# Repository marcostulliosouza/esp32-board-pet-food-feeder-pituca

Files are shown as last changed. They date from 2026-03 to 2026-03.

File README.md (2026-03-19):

# ESP32 Pet Food Feeder – Pituca

<div align="center">
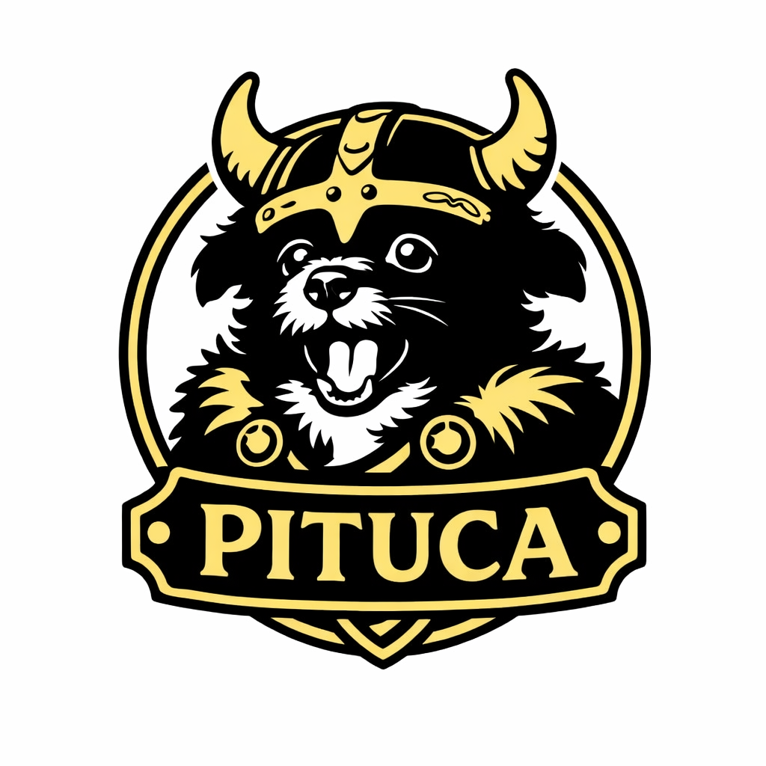
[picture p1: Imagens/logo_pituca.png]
  
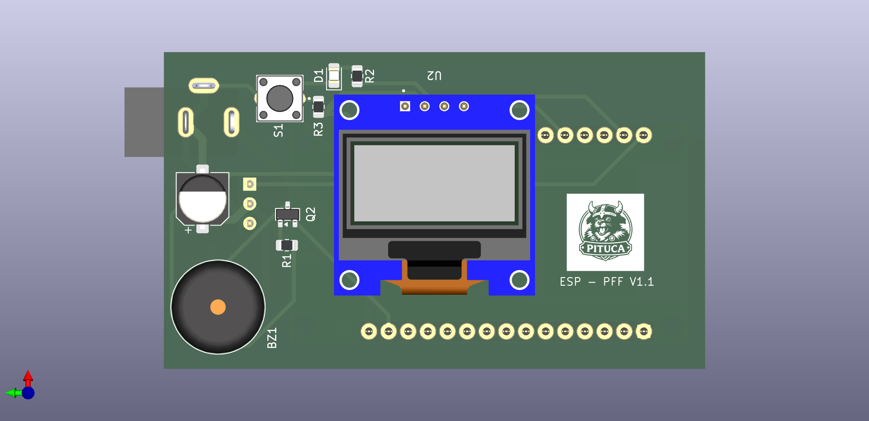
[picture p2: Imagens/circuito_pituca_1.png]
  
</div>

Placa eletrônica baseada no ESP32 desenvolvida para um alimentador automático de pets, permitindo controle preciso de horários e porções de ração, com possibilidade de integração via Wi-Fi.

## Visão geral

Este projeto foi criado para automatizar a alimentação de animais domésticos de forma confiável e prática. A placa utiliza um módulo ESP32 encaixado via headers (socket), facilitando montagem, manutenção e substituição do microcontrolador.

## Funcionalidades

*  Programação de horários de alimentação
*  Conectividade Wi-Fi (ESP32)
*  Alimentação externa regulada
*  Interface para periféricos (motores, sensores, etc.)
*  Design modular com ESP32 removível

##  Hardware

* ESP32 DevKit (via socket)
* Conectores para expansão (GPIOs)
* Trilhas dimensionadas para alimentação e sinais
* Plano de GND em múltiplas camadas

##  Status do projeto

Em desenvolvimento

##  Imagens
imagem_placa_pituca
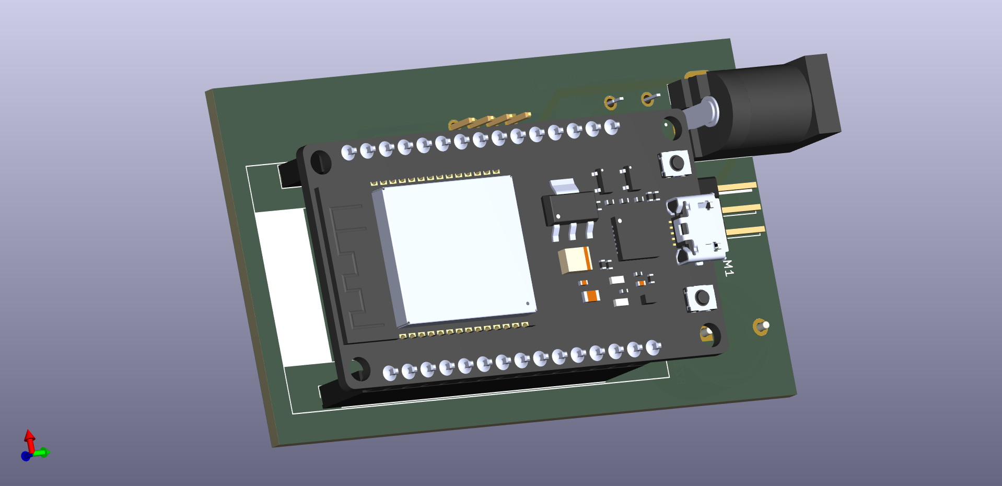
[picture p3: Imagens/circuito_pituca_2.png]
imagem_placa_pituca

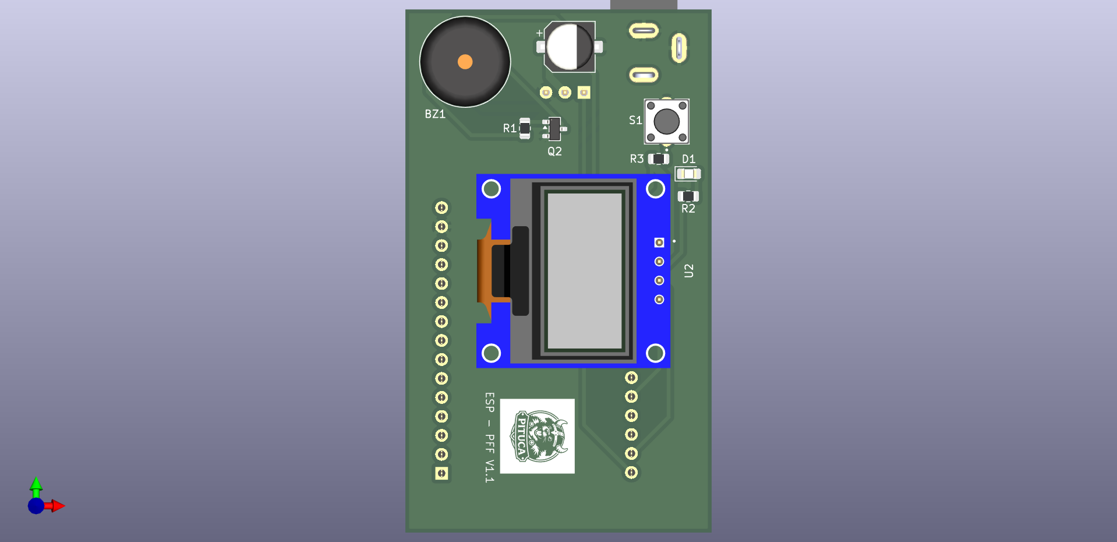
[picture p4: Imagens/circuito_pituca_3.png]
imagem_placa_pituca

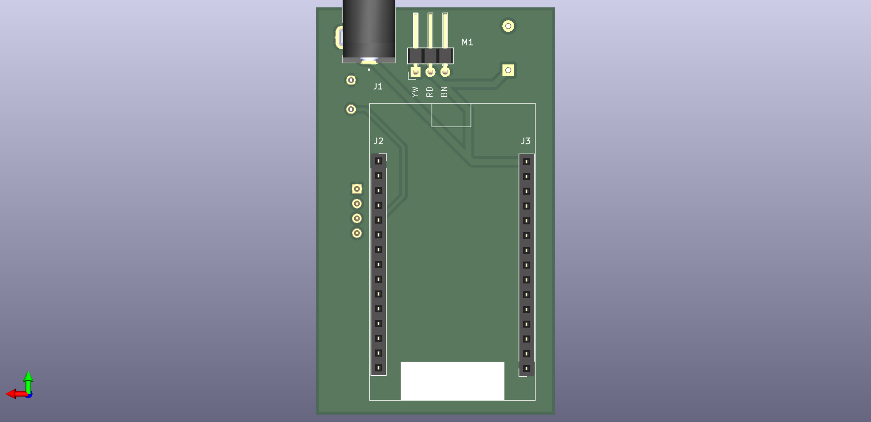
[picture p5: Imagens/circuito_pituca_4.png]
imagem_placa_pituca

## Autor

Projeto desenvolvido por **Marcos Tullio Silva de Souza**

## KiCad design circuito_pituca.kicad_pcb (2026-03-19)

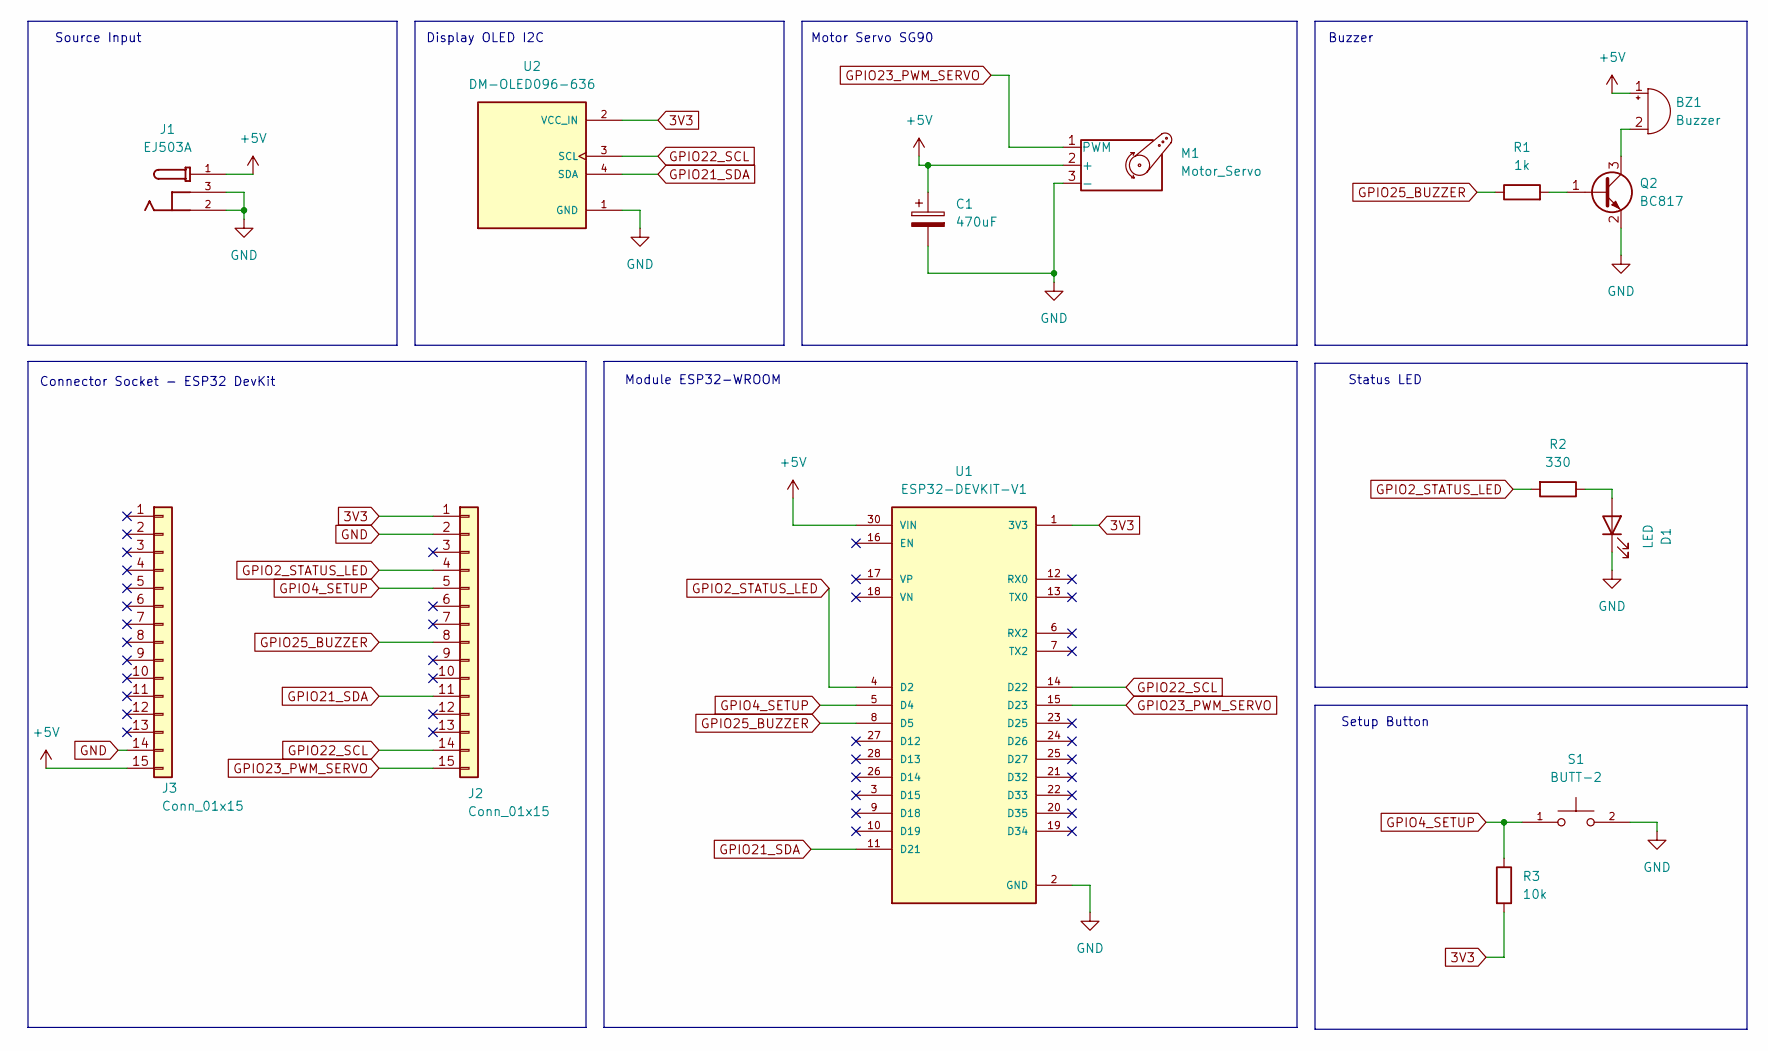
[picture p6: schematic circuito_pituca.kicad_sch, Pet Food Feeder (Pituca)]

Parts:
BZ1: Buzzer; Buzzer_12x9.5RM7.6
C1: 470uF; CP_Elec_6.3x7.7
D1: LED; LED_0805_2012Metric_Pad1.15x1.40mm_HandSolder
J1: EJ503A; MPD_EJ503A; PARTREV B
J2, J3: Conn_01x15; PinSocket_1x15_P2.54mm_Vertical
M1: Motor_Servo; PinHeader_1x03_P2.54mm_Horizontal
Q2: BC817; SOT-23
R1: 1k; R_0805_2012Metric
R2: 330; R_0805_2012Metric
R3: 10k; R_0805_2012Metric
S1: BUTT-2; SW_BUTT-2; PARTREV N/A
U1: ESP32-DEVKIT-V1; MODULE_ESP32_DEVKIT_V1; PARTREV N/A
U2: DM-OLED096-636; MODULE_DM-OLED096-636; PARTREV 2018-09-10

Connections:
3V3: J2.1, R3.2, U1.1 (3V3), U2.2 (VCC_IN)
+5V: BZ1.1 (+), C1.1, J1.1, J3.15, M1.2 (+), U1.30 (VIN)
GND: C1.2, D1.1 (K), J1.2, J1.3, J2.2, J3.14, M1.3 (-), Q2.2 (E), S1.2, U1.2 (GND), U1.29 (GND), U2.1 (GND)
GPIO2_STATUS_LED: J2.4, R2.2, U1.4 (D2)
GPIO4_SETUP: J2.5, R3.1, S1.1, U1.5 (D4)
GPIO21_SDA: J2.11, U1.11 (D21), U2.4 (SDA)
GPIO22_SCL: J2.14, U1.14 (D22), U2.3 (SCL)
GPIO23_PWM_SERVO: J2.15, M1.1 (PWM), U1.15 (D23)
GPIO25_BUZZER: J2.8, R1.1, U1.8 (D5)
unnamed: BZ1.2 (-), Q2.3 (C)
unnamed: D1.2 (A), R2.1
unnamed: Q2.1 (B), R1.2

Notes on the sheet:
Status LED
Setup Button
Connector Socket - ESP32 DevKit
Display OLED I2C
Source Input
Buzzer
Motor Servo SG90
Module ESP32-WROOM

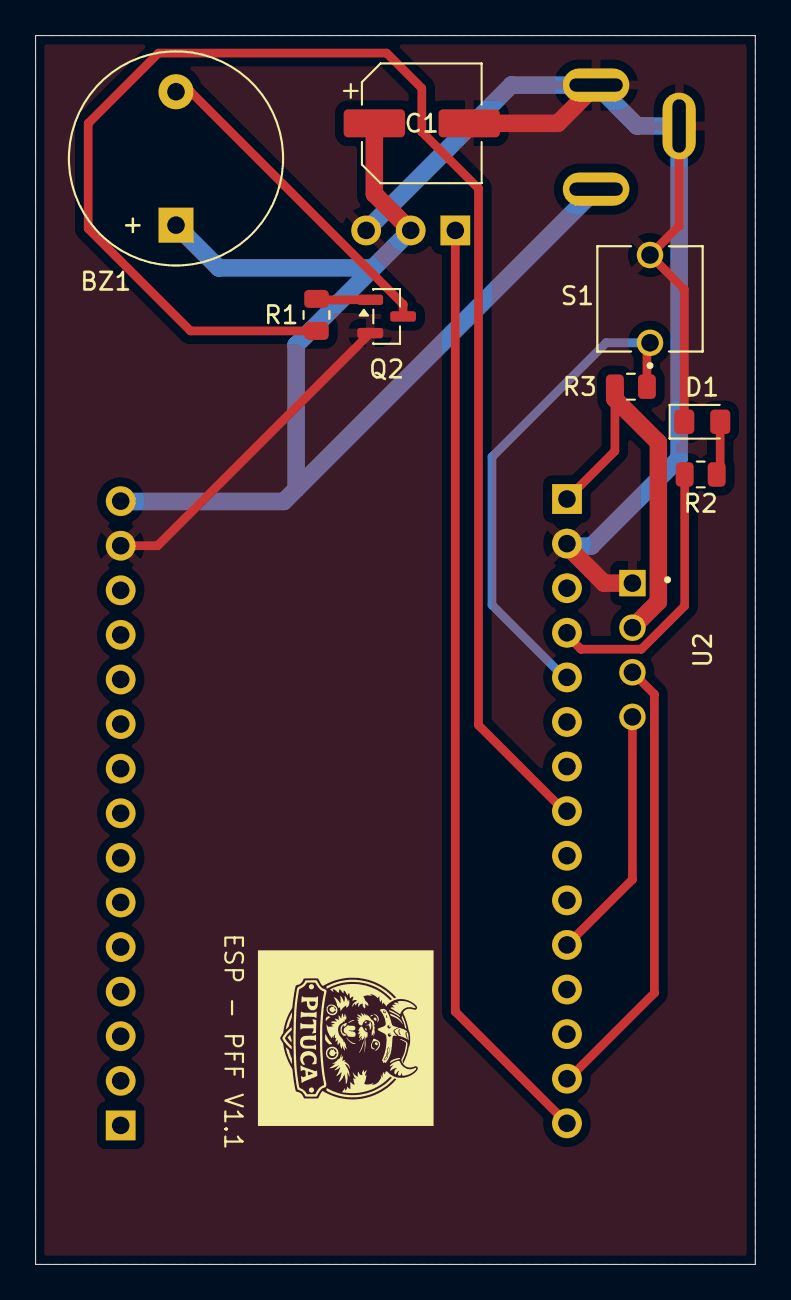
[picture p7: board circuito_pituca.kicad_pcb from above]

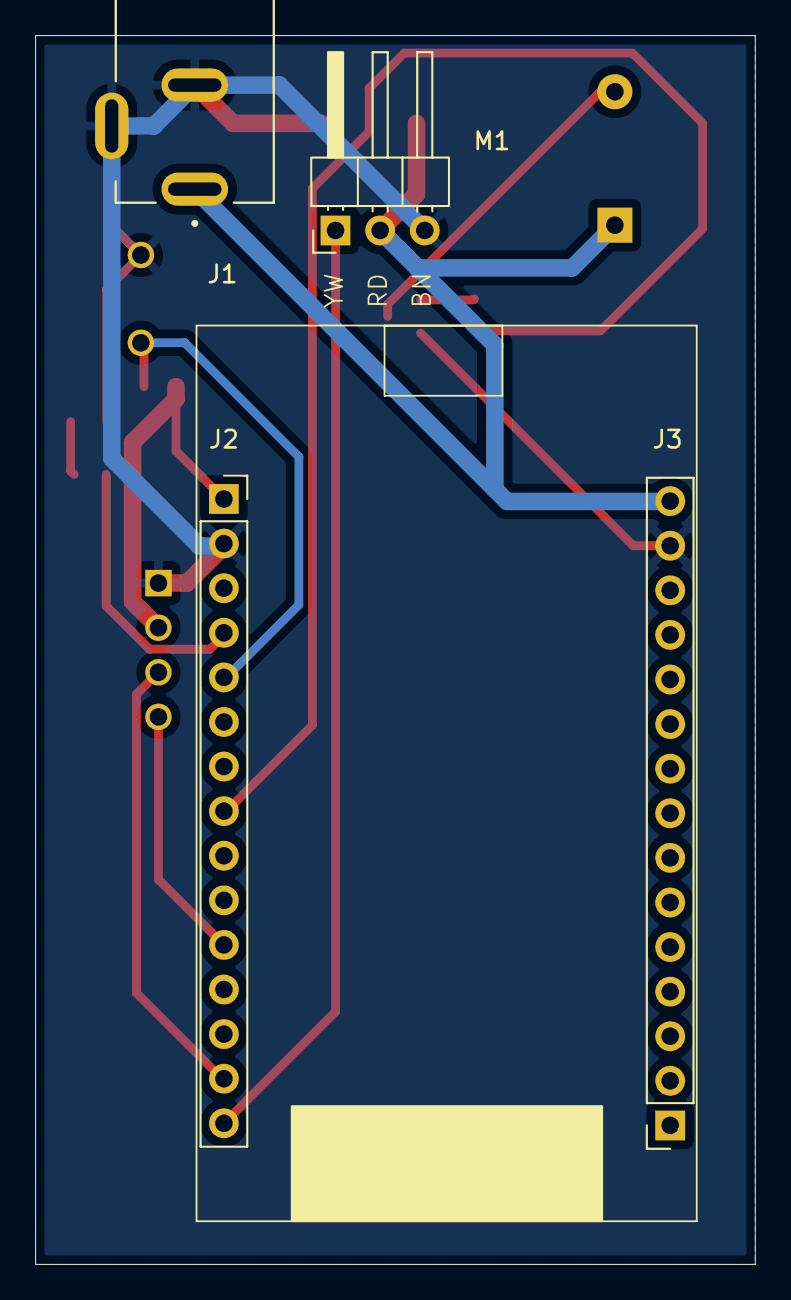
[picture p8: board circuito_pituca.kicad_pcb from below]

Board: 2 copper layers, 41.0 x 70.0 mm, 14 parts (4 on the bottom side), 12 nets.

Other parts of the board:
Logo: LOGO; silk_logo_pituca
